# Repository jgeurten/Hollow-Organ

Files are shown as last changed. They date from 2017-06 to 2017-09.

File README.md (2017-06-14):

# Cardiac-Organ

Repo containing firmware to drive the Pololu Nema 23 item 1477 stepper motor (8.6V, 1A/phase) 190 oz-in torque using the Adafruit 'Big Easy Driver' powered by the A4988 IC.
Also included is the computer aided designed parts and assemblies designed in SolidWorks.

Adafruit Feather 32u4 BLE is the MCU on board the apparatus and uses a rotary encoder to create a closed loop feedback system enabling the usage of a PID controller.

Jordan Geurten

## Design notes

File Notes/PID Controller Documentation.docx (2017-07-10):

PID Controller Documentation

The figure bellows demonstrates a typical closed loop system for which a PID controller is modelled.

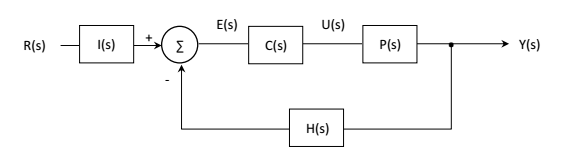
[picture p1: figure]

In PID theory, all transfer functions (e.g. R(s) are a function of s as per the Laplace domain).

R(s), the reference signal, is the input signal to the system. The difference between the output signal (Y(s)) and the reference signal should be minimized, by the closed loop system.

I(s), the input filter transfer function, converts the input signal to a usable form for the controller.

C(s), the controller transfer function, is the brain of the system, responsible for minimizing error between the reference and output. PID (proportional plus integral plus derivative controllers) are a type of controller transfer function. For PID, C(s) is equal to the expression below:

C(s)=(KdS^2 +KpS+Ki)/s (1)

E(s), error signal, is the difference between the output of the input filter function and the feedback transfer function H(s).

U(s), controller output signal, is the signal that the controller calculates and applies to the plant (in our case, the rotating jig and its associated physical terms like inertia).

Plant Transfer function P(s)

The plant transfer function is derived using one of two techniques. The first technique, ‘First Principles Techniques’ can be used when enough information is known about the system. For a mechanical system, a free body diagram of the plant is created, to which Newton’s Second Laws of motion are applied. For the rotating jig system, rotational motion is the focus:

∑ Τ=Ia (2)

The second approach, ‘Transient and Steady-State Response Analysis’ is used when scarce amounts of information is known about the plant. A known signal is applied to the plant, such as a step function of an arbitrary voltage value, and the steady – state response of the plant is analyzed.

Rotating Jig Plant Specs:

It is essential for the controller function, more specifically determining the gain values for the controller in equation 1, to determine the performance specifications of the system. Since the jig will rotate for 30 – 60 minutes, rise time will be ignored. Furthermore, maximum overshoot is not of utmost importance, either. For this reason, maximum percent overshoot will be limited to 25% for a step input. Lastly, zero steady-state error for a step input is also required. In other words, the actual speed of the system minus the desired speed of the system will equal zero.

The specifications of the system can be summarized as the following:

1. Maximum percent overshoot < 25% for a step input (derivative controller)
2. Steady-state error = 0 for a step input (Integral controller)

For these specifications, a

Modelling Each Element:

1. Stepper Motor System:

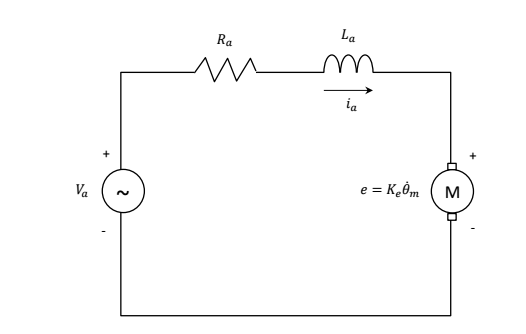
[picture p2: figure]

Using KVL on the motor’s electric armature results in:

0=Ri+L(di)/(dt)+Keϑ-V (3)

According the stepper motor’s datasheet (pololu.com/product/1477), the Nema 23 stepper has the following specs:

R = 8.6 Ohms

I

Spec | Value
R | 8.6 Ohms
i | 0.06 A
V | 12 V
L | 0.014 H
Ke | ??

2. DC Motor System:

Spec | Value
R | 8.6 Ohms
i | 0.06 A
V | 12 V
L | 0.014 H
Ke | ??

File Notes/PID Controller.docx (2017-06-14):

PID Controller – Motor Speed & Arduino

PID controller for speed reference:

http://ctms.engin.umich.edu/CTMS/index.php?example=MotorSpeed&section=ControlPID

Arduino Reference:

http://blog.solutions-cubed.com/pid-motor-control-with-an-arduino/

*Need to think if it is worth the extra work of implementing a PID controller (think testing, too) for the spinning jig project*

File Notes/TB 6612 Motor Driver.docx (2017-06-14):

TB 6612 Motor Driver – ADAFRUIT

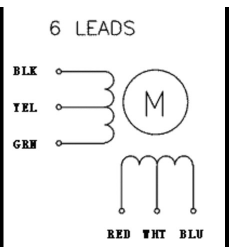
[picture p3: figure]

1. Power Pins

Vmotor – connect to battery + terminal (4.5V to 13.5V)

Vcc – connect to 3V on Feather. Voltage for logic levels (i.e. reference). Power the chip.

GND – connect all the grounds together. Shared logic and motor ground.

2. Motor out Pins

Motor A – controlled by INA1, INA2, PWMA

Motor B – same as above but with suffix ‘B’

3. Signal in Pins

INA – inputs to the motor H-bridges

PWMA – PWM input. Connect to HIGH if PWM is unnecessary

STBY – disabling motors. Connect to GND to disable. Pulled up to Vcc through a 10k resistor (built-in I believe).

Channel Configuration

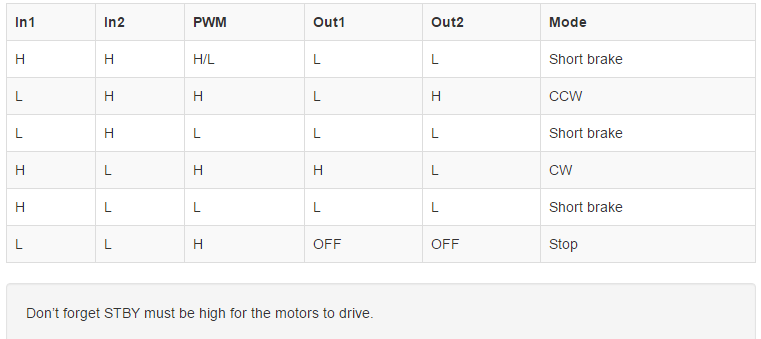
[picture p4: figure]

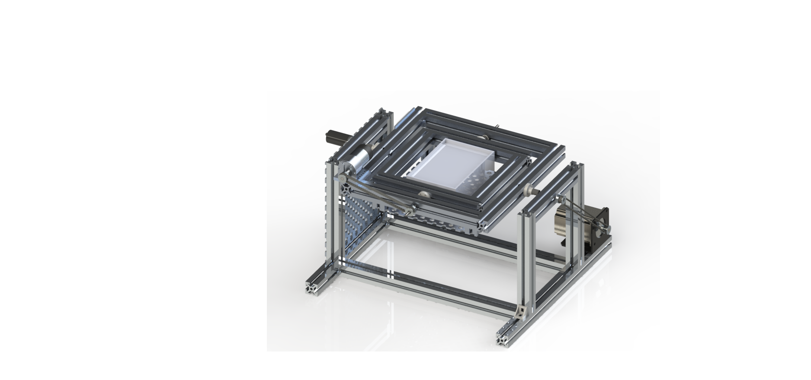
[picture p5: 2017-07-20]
Final Rendering.png

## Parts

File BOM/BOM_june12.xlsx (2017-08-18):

BOM # | Quantity | Description | Link | Length | ID | Purpose | Cost
1 | 2 | T Slotted Handle | https://www.mcmaster.com/#47065t164/=181dc2a | n/a |  | Handles for external frame | $12.80
2 | 1 | MXL Timing Belt | https://www.mcmaster.com/#7887k225/=18dpk54 | 12.2 |  | Belt for DC Motor | $3.48
3 | 1 | MXL Timing Belt | https://www.mcmaster.com/#7887k91/=18dpllq | 20 |  | Belt for Stepper Motor | $5.77
5 | 1 | Spacer Stock | https://www.mcmaster.com/#92377a310/=181ffhf | 12 inch | 0.192 | Spacer for rotary shafts | $4.44
6 | 2 | T Slotted Framing | https://www.mcmaster.com/#47065t801/=186kah1 | 6.5 inch |  | Inner-most gantry | $7.98
7 | 2 | T Slotted Framing | https://www.mcmaster.com/#47065t801/=186kah1 | 8.5 inch |  | Inner-most gantry | $10.26
8 | 4 | T Slotted Framing | https://www.mcmaster.com/#47065t801/=186kah2 | 1.5 inch |  | Inner-most gantry | $4.56
9 | 2 | T Slotted Framing | https://www.mcmaster.com/#47065t801/=186kah3 | 10 inch |  | Outer gantry | $11.40
10 | 2 | T Slotted Framing | https://www.mcmaster.com/#47065t801/=186kah3 | 12 inch |  | Outer gantry | $13.68
11 | 4 | T Slotted Framing | https://www.mcmaster.com/#47065t801/=186kah4 | 8.25 inch |  | Frame | $20.52
12 | 2 | T Slotted Framing | https://www.mcmaster.com/#47065t801/=186kah5 | 6.5 inch |  | Frame | $7.98
13 | 2 | T Slotted Framing | https://www.mcmaster.com/#47065t801/=186kah6 | 14.5 inch |  | Frame | $17.10
14 | 2 | T Slotted Framing | https://www.mcmaster.com/#47065t801/=186kah7 | 16 inch |  | Frame | $18.24
15 | 40 | Framing Brace | https://www.mcmaster.com/#47065t216/=18jckzp | 1 inch |  | Framing brace | $220.40
16 | 1 (PACK OF 10) | Threaded Rod | https://www.mcmaster.com/#95412a891/=18dok42 | 3 INCH | 10-24 | Securing mold to gantry | $7.42
17 | 4 | 4 Arm Threaded Knob | https://www.mcmaster.com/#5993k13/=18dol11 | 0 | 10-24 | Securing mold to gantry | $6.48
18 | 1 (PACK OF 50) | S.S. Hex Nut | https://www.mcmaster.com/#91841a011/=18dolm5 | 0 | 10-24 | Securing mold to gantry | $3.50
19 | 1 | DC Motor L-Bracket | https://www.pololu.com/product/1084 | 0 |  | Securing DC motor | $7.95
20 | 1 | Stepper Motor L-Bracket | https://www.pololu.com/product/2258 | 0 |  | Securing Stepper Motor | $4.95
21 | 1 | Mounting plate (3"x3") | https://www.mcmaster.com/#47065t854/=188kx18 | 3x3 |  | Securing Stepper to Rig | $12.56
22 | 2 | Mounting plate (3" x 1.5") | https://www.mcmaster.com/#47065t853/=188kxoe | 3x1.5 |  | DC motor circuit/MCU | $24.28
23 | 1 | Mounting plate (2" x 2") | https://www.mcmaster.com/#47065t852/=188kyri | 2x2 |  | DC Motor mount | $11.32
24 | 2 | NiCad Battery 12 Volt 1800 mAh | https://www.digikey.ca/product-detail/en/panasonic-bsg/KR1800SCEL5X2/SY156-L052-ND/1985934 | 8.33 inch |  | Battery for stepper and DC motor | $144.86
25 | 2 | LiPoly Battery 3.V 500 mAh | https://elmwoodelectronics.ca/products/lithium-ion-polymer-battery-3-7v-500mah | 1.15 inch |  | Battery for MCUs | $23.98
26 | 1 | NiCad Battery Charger (180 mA) | https://elmwoodelectronics.ca/products/10473 | N/A |  | Charging for NiCad Bat | $43.99
27 | 2 | JST Cable Set | https://elmwoodelectronics.ca/products/2-pin-jst-sm-plug-receptacle-cable-set | 16 cm |  | For NiCd Battery | $6.98
28 | 2 | JST Male | https://elmwoodelectronics.ca/products/jst-2-pin-cable | 10 cm |  | For NiCd Battery | $6.98
29 | 2 | JST Extension | https://elmwoodelectronics.ca/products/jst-ph-battery-extension-cable-500mm | 50 cm |  | For NiCd Battery | $9.18
30 | 8 | Sealed Ball Bearing | https://www.mcmaster.com/#60355k861/=18dprn8 | 0.2 | 3/16 |  | $24.96
 |  |  |  |  |  |  | $673.04

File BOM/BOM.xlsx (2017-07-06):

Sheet: Sheet1
Bill of Materials |  | List Number | Quantity | Part Number | Description | ID (in) | OD (in) | Pitch (in) | # Teeth | Max Belt Width | Length (in) | Website Hyperlink
Project: | Rotating Jig | 1 | 2 | 1375K36 | Timing Belt Pulley | 3/16 | 0.635 | 0.08 | 18 | 1/4 |  | https://www.mcmaster.com/#1375k36/=17jge2d
Engineer: | Jordan Geurten | 2 | 8 | 60355K502 | Ball Bearing | 3/16 | 0.5 | N/A | N/A | N/A | 5/32 | https://www.mcmaster.com/#60355k502/=17jgp9q
 |  | 3 | 2 | 1327K53 | 12L14 Carbon Steel Shaft | N/A | 3/16 | N/A | N/A | N/A | 12 | https://www.mcmaster.com/#1327k53/=17jgfdh
* Spare parts |  | 4 | 4 | 6436K6 | Face Mount Shaft Collar | 3/16 | 5/8 | N/A | N/A | N/A | 5/16 | https://www.mcmaster.com/#6436k6/=17jghuk
^* To start and stop the device |  | 5 | 1 | 90044A111 | 4-40 Alloy Steel Socket Head Scres | 0.112 | 0.183 | N/A | N/A | N/A | 1 | https://www.mcmaster.com/#90044a111/=17jgmsh
 |  | 6 | 2 |  | Low Speed Torque Stepper Motor |  | https://www.pololu.com/category/87/stepper-motors
 |  | 7 | 4 |  | Rechargable Battery
 |  | 8 | 2 |  | Arduino Microcontroller
 |  | 9 | 2 |  | Stepper Motor Controller
 |  | 12 |  |  | Drive Belts

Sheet: Stepper Motor
List Number | Quantity | Part Number | Description | Holding Torque | Steps/rev | Current Draw (A) | Voltage (v) | Shaft Diam | Size | Belt Size | Price per unit | Total Price | Website Hyperlink
6 | 2 | 1477 | Pololu Stepper Motot | 14kg-cm | 200 | 1 | 8.6 | 6.35mm | 56.4*76 |  | $49.95 | $99.90 | https://www.pololu.com/product/1477
7 | 2 | 1375K39 | Timing Belt Pulley |  |  |  |  | For 6.35mm |  | 1/4 " | $10.79 | $21.58 | https://www.mcmaster.com/#1375k39/=17oixwq
8 | 2 | 2448 | Stepper Motor Driver |  |  | <1.2 | 5-13.5 |  |  |  | 4.95 | $9.90 | https://www.adafruit.com/product/2448
9 | 2 | 2829 | Microcontroller with BLE |  |  |  |  |  |  |  | 29.95 | $59.90 | https://www.adafruit.com/product/2829
10 | 2 | 2830 | Stacking Headers |  |  |  |  |  |  |  | 1.25 | $2.50 | https://www.adafruit.com/product/2830
11 | 1 |  | Power pigtails |  |  |  |  |  |  |  | 3.61 | $3.61 | https://www.amazon.ca/uxcell-5-5X2-1mm-Connector-Pigtail-Camera/dp/B01L7NC85S
12 | 2 |  | Power Banks |  |  |  |  |  |  |  | 84.99 | $169.98 | https://www.amazon.ca/dp/B01LRW4DUC?psc=1
 |  |  |  |  |  |  |  |  |  |  | total: | $367.37

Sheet: Battery Packs
http://www.batteryspace.com/custom-nimh-battery-flat-pack-12v-2200mah-10xaa-with-2a-polyswitch.aspx
12 V
2200 mAh
https://www.amazon.ca/RAVPower-23000mAh-Portable-External-Smartphones/dp/B00HFMUBYG
12V
23000 mAh
https://www.newegg.com/Product/Product.aspx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
12V
20000mAh

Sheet: Mcmaster Carr
List Number | Quantity | Part Number | Description | ID (in) | OD (in) | Pitch (in) | # Teeth | Max Belt Width | Length (in) | Website Hyperlink
1 | 2 | 1375K36 | Timing Belt Pulley | 3/16 | 0.635 | 0.08 | 18 | 1/4 |  | https://www.mcmaster.com/#1375k36/=17jge2d
2 | 8 | 60355K502 | Ball Bearing | 3/16 | 0.5 | N/A | N/A | N/A | 5/32 | https://www.mcmaster.com/#60355k502/=17jgp9q
3 | 2 | 1327K53 | 12L14 Carbon Steel Shaft | N/A | 3/16 | N/A | N/A | N/A | 12 | https://www.mcmaster.com/#1327k53/=17jgfdh
4 | 4 | 6436K6 | Face Mount Shaft Collar | 3/16 | 5/8 | N/A | N/A | N/A | 5/16 | https://www.mcmaster.com/#6436k6/=17jghuk
5 | 1 | 90044A111 | 4-40 Alloy Steel Socket Head Scres | 0.112 | 0.183 | N/A | N/A | N/A | 1 | https://www.mcmaster.com/#90044a111/=17jgmsh

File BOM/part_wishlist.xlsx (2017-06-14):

List Number | Quantity | Part Number | Description | Price per unit | Total Price | Website Hyperlink
6 | 1 | 1477 | Pololu Stepper Motor | $49.95 | $49.95 | https://www.pololu.com/product/1477
7 | 2 | 1375K39 | Timing Belt Pulley | $10.79 | $21.58 | https://www.mcmaster.com/#1375k39/=17oixwq
8 | 1 | 2448 | Stepper Motor Driver | $4.95 | $4.95 | https://www.adafruit.com/product/2448
9 | 2 | 2829 | Microcontroller with BLE | $29.95 | $59.90 | https://www.adafruit.com/product/2829
10 | 2 | 2830 | Stacking Headers | $1.25 | $2.50 | https://www.adafruit.com/product/2830
11 | 1 |  | Power pigtails | $3.61 | $3.61 | https://www.amazon.ca/uxcell-5-5X2-1mm-Connector-Pigtail-Camera/dp/B01L7NC85S
12 | 2 |  | Power Banks | $84.99 | $169.98 | https://www.amazon.ca/dp/B01LRW4DUC?psc=1
13 | 1 | COM-10932 | Rotary Encoder | $39.95 | $39.95 | https://www.sparkfun.com/products/10932
15 | 1 |  | Brushed DC Motor with Encoder | $51.94 | $51.94 | https://www.pololu.com/product/2824
16 | 1 | 976 | TIP 120 Transistor | $2.50 | $2.50 | https://www.adafruit.com/product/976
17 | 1 | 755 | 1N4001 Diodes | $1.50 | $1.50 | https://www.adafruit.com/product/755
18 | 1 | 753 | 0.1 uF Capacitors | $1.95 | $1.95 | https://www.adafruit.com/product/753
19 | 1 | 1214 | 3 Pack Protoboard PCB | $7.95 | $7.95 | https://www.adafruit.com/product/1214
20 | 2 | MCP602T-I/SN | Integrated Circuit Microchip | $0.92 | $1.84 | https://www.digikey.ca/product-detail/en/microchip-technology/MCP602T-I-SN/MCP602T-I-SNCT-ND/5013529
21 | 2 | IRLZ44NPBF | MOSFET Transistor | $1.44 | $2.88 | https://www.digikey.ca/product-detail/en/infineon-technologies/IRLZ44NPBF/IRLZ44NPBF-ND/811808
 |  |  |  | total: | $418.25

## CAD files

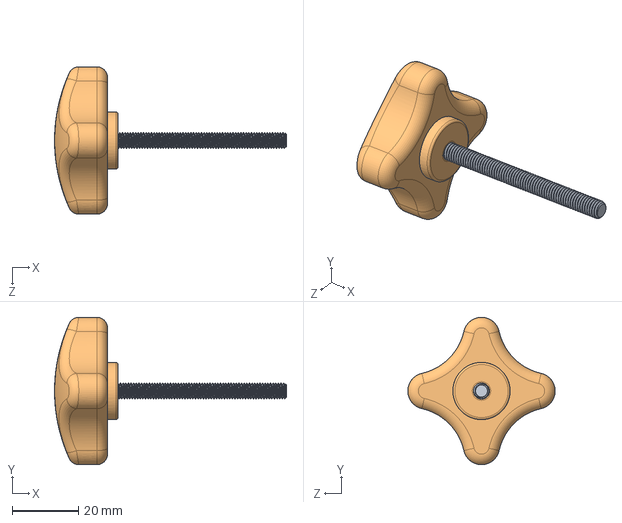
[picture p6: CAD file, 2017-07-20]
CAD/Assemblies/Mold_Clamp_revB.SLDASM
70.0 x 44.4 x 44.4 mm
10-32_rod
threaded_four_arm_knob

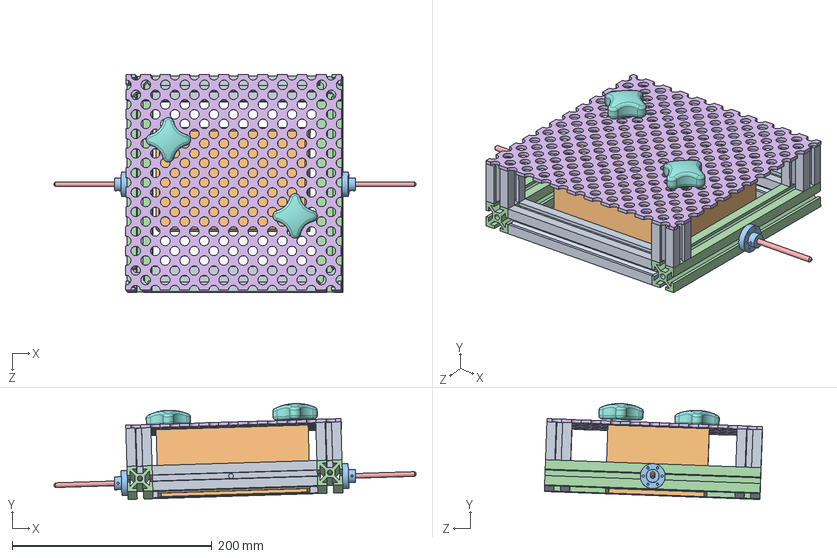
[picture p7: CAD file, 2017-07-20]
CAD/Assemblies/Inside Gantry.SLDASM
362.5 x 96.1 x 218.2 mm
1_1_frame_6_8inch x 2
Kidney_Mold
Face_Shaft_Collar_revA x 2
1_1_frame_7inch x 2
rotary_shaft x 2
framing_panel_inside
10-32_rod x 2
threaded_four_arm_knob x 2
1_1_frame_1_inch x 4

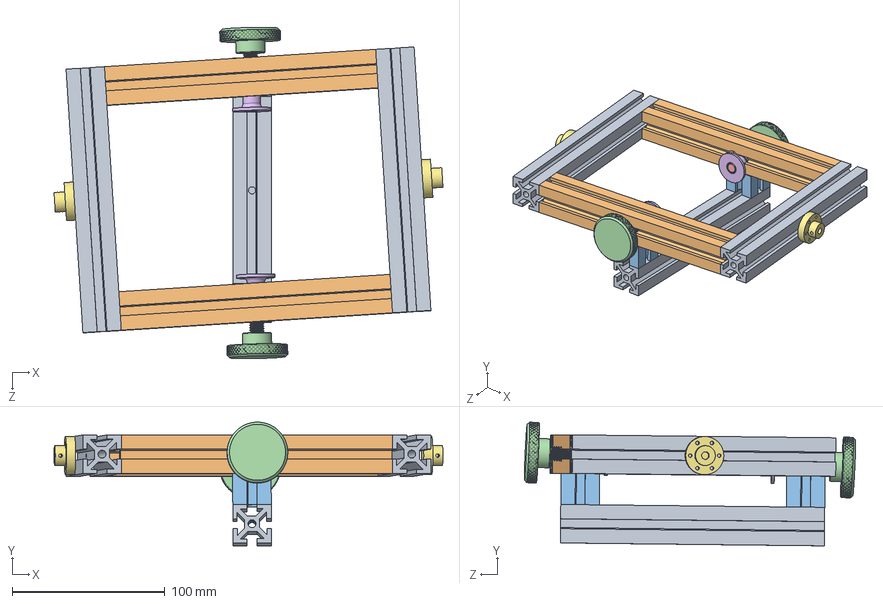
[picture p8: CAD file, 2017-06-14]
CAD/Assemblies/Mold_Jig.SLDASM
254.5 x 81.0 x 216.8 mm
1_1_frame_6_8inch x 3
1_1_frame_7inch x 2
1_1_frame_0_8_inch x 2
Knurled_Knob x 2
Threaded_Rod_Clamp x 2
Base_Nut x 2
Face_Shaft_Collar_revA x 2

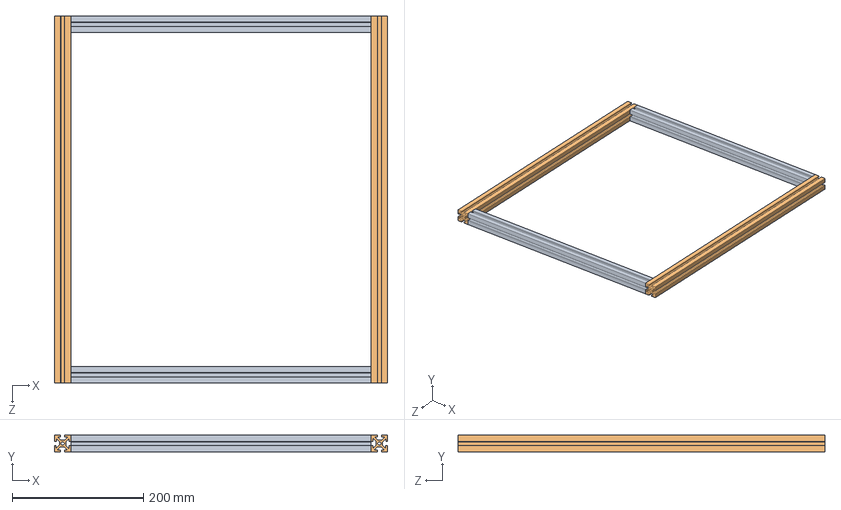
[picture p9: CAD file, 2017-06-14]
CAD/Assemblies/external_frame_top_bot.SLDASM
507.6 x 25.2 x 558.8 mm
1_1_frame_18_inch x 2
1_1_frame_22_inch x 2

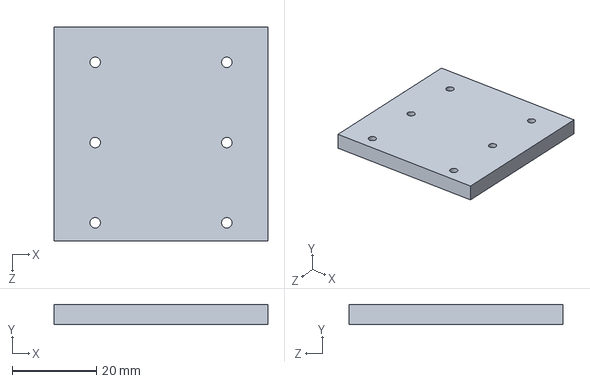
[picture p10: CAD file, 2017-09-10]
CAD/SLDPRTs/dc_motor_platform_alumin.SLDPRT
50.8 x 4.83 x 50.8 mm

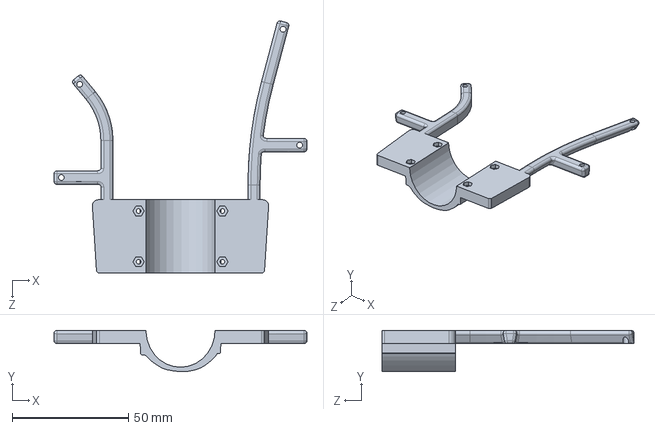
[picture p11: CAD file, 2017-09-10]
CAD/SLDPRTs/laser_drb_revB.SLDPRT
108.9 x 17.8 x 108.6 mm

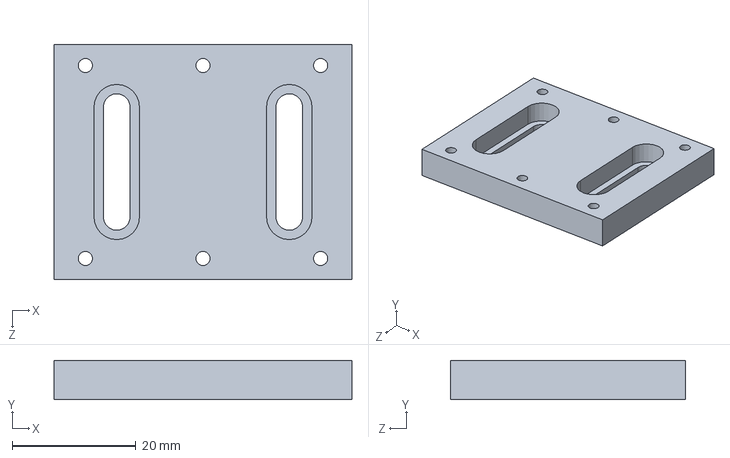
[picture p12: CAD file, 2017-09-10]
CAD/SLDPRTs/dc_motor_platform.SLDPRT
48.3 x 6.35 x 38.1 mm

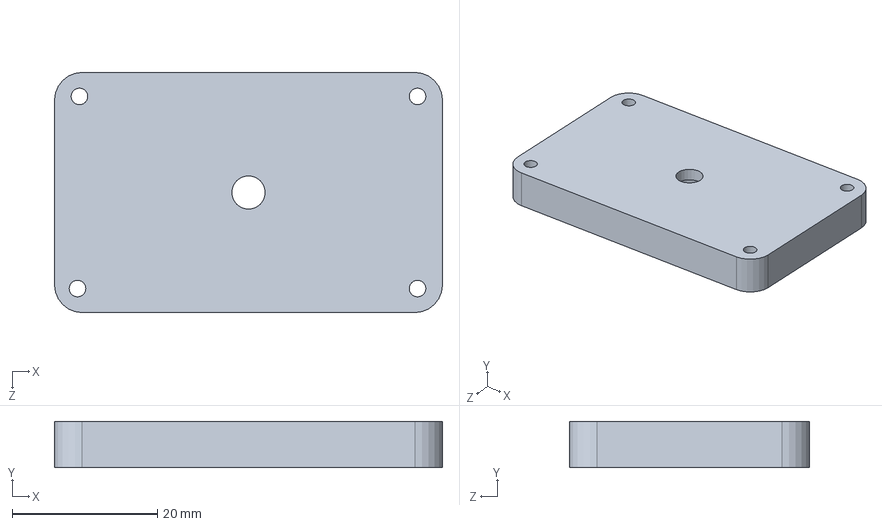
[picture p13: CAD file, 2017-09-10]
CAD/SLDPRTs/dc_mcu_platform.SLDPRT
53.3 x 6.35 x 33.0 mm

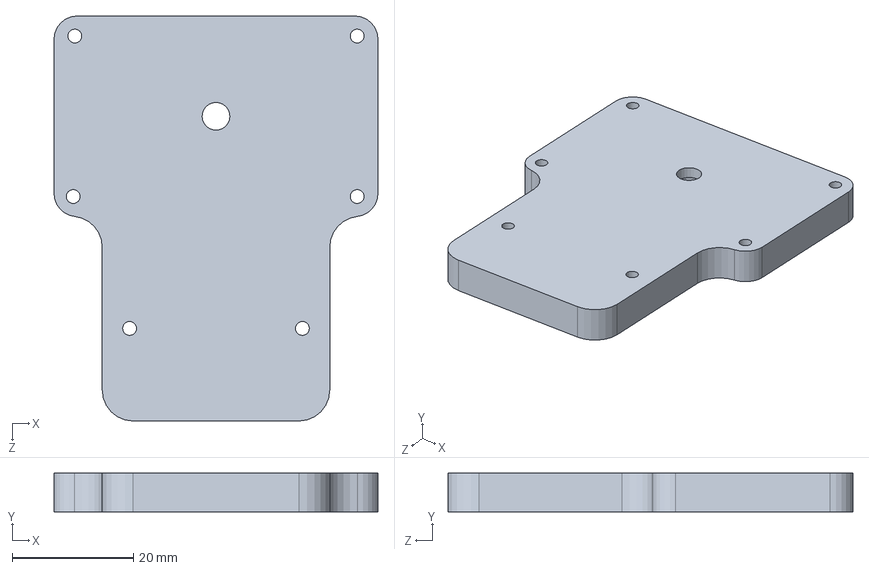
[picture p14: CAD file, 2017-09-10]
CAD/SLDPRTs/stepper_driver_platform.SLDPRT
53.3 x 6.35 x 66.7 mm

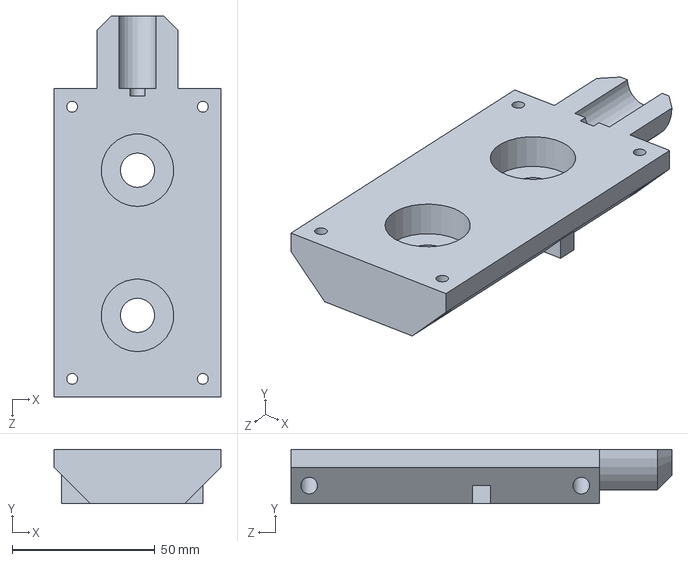
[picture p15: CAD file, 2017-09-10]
CAD/SLDPRTs/Endo_top_half.SLDPRT
58.4 x 19.1 x 133.4 mm

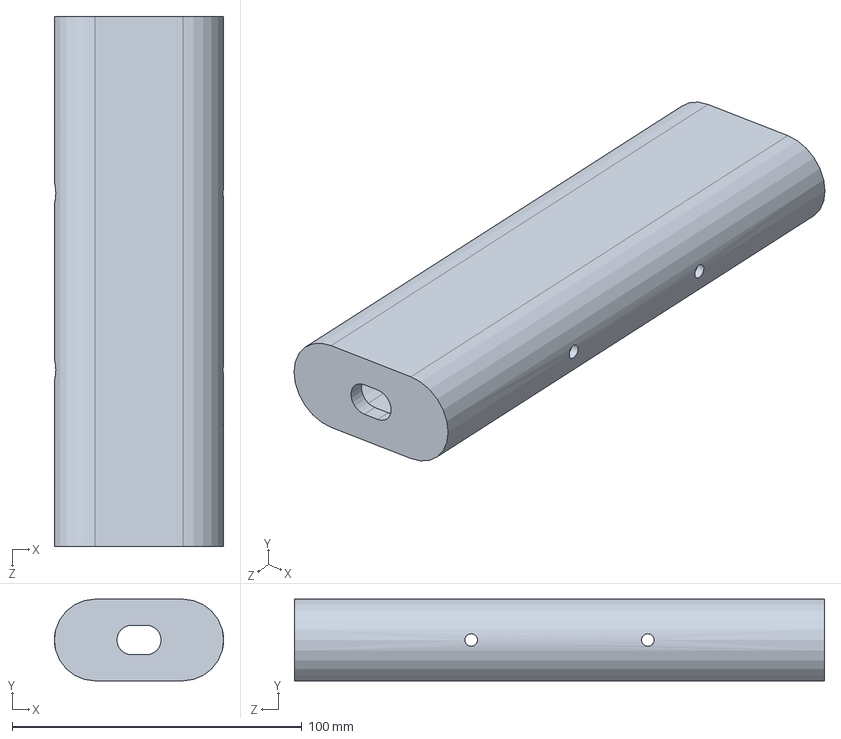
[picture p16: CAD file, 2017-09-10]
CAD/SLDPRTs/battery_shield_RevB.SLDPRT
58.4 x 28.2 x 182.9 mm

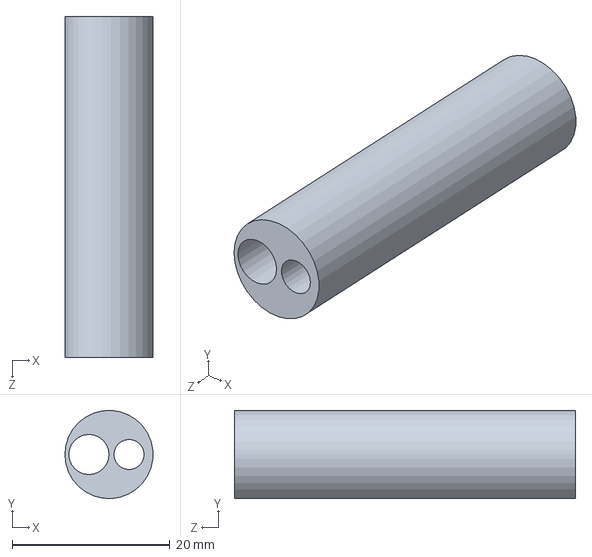
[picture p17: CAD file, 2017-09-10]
CAD/SLDPRTs/laserSheath.SLDPRT
11.2 x 11.2 x 43.2 mm

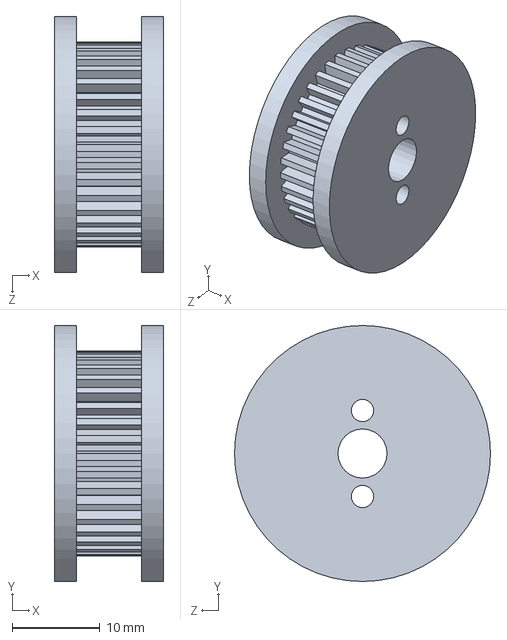
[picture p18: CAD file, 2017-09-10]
CAD/SLDPRTs/2to1_TimingBelt.SLDPRT
12.4 x 29.1 x 29.1 mm

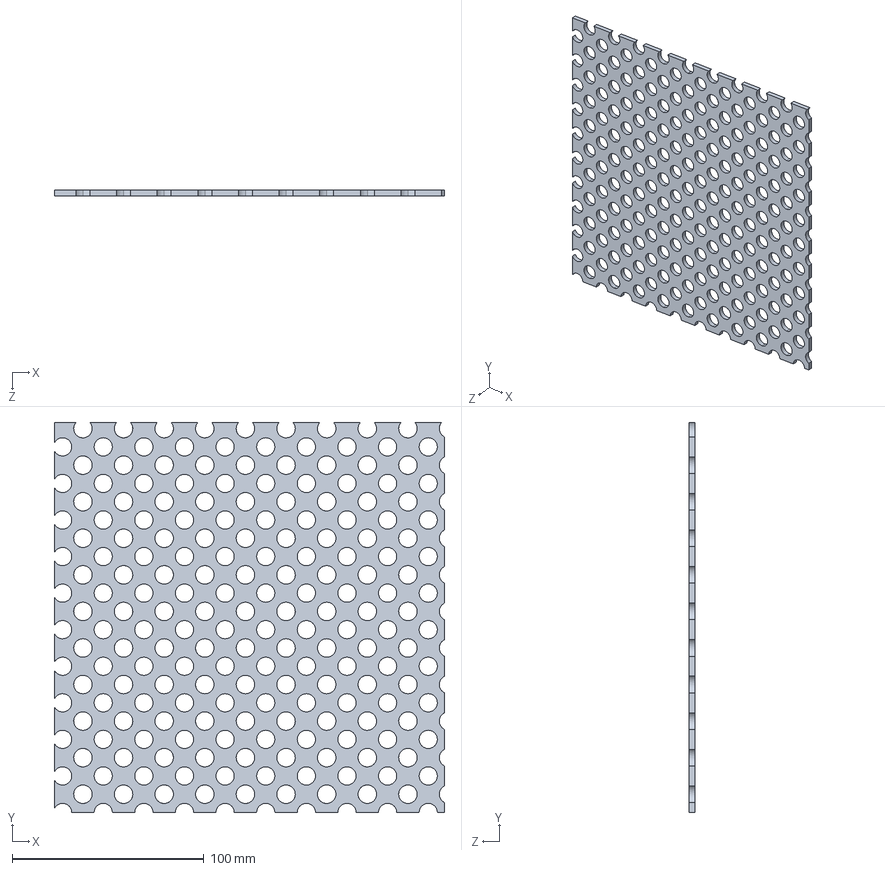
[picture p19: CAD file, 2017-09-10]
CAD/SLDPRTs/framing_panel.SLDPRT
203.2 x 203.2 x 3.17 mm

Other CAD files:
CAD/SLDPRTs/MCU_Battery_shield.SLDPRT
CAD/Assemblies/Mold_Clamp.SLDASM
CAD/Assemblies/Mold_Clamp_revA.SLDASM
CAD/SLDPRTs/10-32_rod.SLDPRT
CAD/SLDPRTs/1375K110_MXL SERIES TIMING BELT PULLEY.SLDPRT
CAD/SLDPRTs/1_1_frame_0_8_inch.SLDPRT
CAD/SLDPRTs/1_1_frame_18_inch.SLDPRT
CAD/SLDPRTs/1_1_frame_1_inch.SLDPRT
CAD/SLDPRTs/1_1_frame_22_inch.SLDPRT
CAD/SLDPRTs/1_1_frame_6_8inch.SLDPRT
CAD/SLDPRTs/1_1_frame_7inch.SLDPRT
CAD/SLDPRTs/1_1_frame_true18_inch.SLDPRT
CAD/SLDPRTs/1by1by10inch_frame.SLDPRT
CAD/SLDPRTs/1by1by11inch_frame.SLDPRT
CAD/SLDPRTs/1by1by4_5inch_frame.SLDPRT
CAD/SLDPRTs/1by1by9inch_frame.SLDPRT
CAD/SLDPRTs/2776K200_POLYPROPYLENE COMFORT-GRIP 3-ARM KNOB.SLDPRT
CAD/SLDPRTs/47065T164_ALUMINUM T-SLOTTED FRAMING EXTRUSION.SLDPRT
CAD/SLDPRTs/47065T216_ALUMINUM T-SLOTTED FRAMING EXTRUSION.SLDPRT
CAD/SLDPRTs/47065T901_ALUMINUM T-SLOTTED FRAMING EXTRUSION.SLDPRT
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

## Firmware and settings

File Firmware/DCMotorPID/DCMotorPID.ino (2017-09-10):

   ///////////////////////////////////////////////////////////////////////////////////////////
  // DC Motor PID Controller Code
  // Version 1, July 10
  // Jordan Geurten
  ///////////////////////////////////////////////////////////////////////////////////////////
  
  #include <math.h>
  #include <MsTimer2.h>
  
  ///////////////////////////////////////////////////////////////////////////////////////////
  // Motor pins
  ///////////////////////////////////////////////////////////////////////////////////////////
  
  unsigned int stopPin =     1;             //feather interrupt pin2
  unsigned int startPin =    0;             //feather interrupt pin3
  unsigned int encoderPin =  2;             //feather interrupt pin1
  unsigned int voltagePin =  3;             //feather interrupt pin0
  unsigned int motorPin =    5;

  unsigned int Motor_Current;               //Pin to read current input from motor controller. WAit, we dont have a motor controller. 
  
  //Global variables:
  
  volatile byte Go = 0;                      //Interrupt flag for START
  volatile byte Stop = 0;                    //Interrup flag for STOP
  volatile double Error = 0;                 //Ref_Speed Error
  volatile double prevError = 0;             //Prev Ref_Speed Error
  volatile double KpOutput = 0;              //Proportional output
  volatile double KiOutput = 0;              //Integral output
  volatile double KdOutput = 0;              //Derivative output
  volatile double Controller_Input = 0;       //Output from Error calc
  volatile double VtoPWM = 0;                //Define relation between voltage and pwm
  volatile double Integral= 0;               //Integral of the error
  
  volatile unsigned long edgeCount = 0;      //Encoder edge count
  volatile double Motor_Speed = 0;            //Motor Ref_Speed in RPM
  volatile float Elapsed_Time = 0;           //Elapsed time of the test
  volatile double startTime = 0;             //Store last time start button was pressed
  volatile double stopTime = 0;              //Store last stop button time
  
  ///////////////////////////////////////////////////////////////////////////////////////////
  //User defined variables:
  ///////////////////////////////////////////////////////////////////////////////////////////
  
  double Kp = 0;                             //Proportional gain
  double Ki = 0;                             //Integral gain
  double Kd = 0;                             //Derivative gain
  
  //Define input voltage
  float V_in  = 12.0;
  
  //Timer timeout period in ms
  static unsigned int Period = 50;
  
  //Desired Speed [in RPM]
  static unsigned int Ref_Speed =  30;
  
  //Open loop variables [in RPM]
  volatile float Ref_Input = 0;

  //Open loop variable - step input [PWM]
  volatile float Step_Input = 0;

  //Duration of the test [in seconds]:
  volatile float Time = 5 * 60;           //5 minute test * 60 secs/min 

  

  //
  //////////////////////////////////////////////////////////////////////////////////////////
  // Mode of Operation:
  //
  //      0 = Open Loop Step    -- applies a constant voltage to motor
  //                            Inputs  ---------------------------------------------------
  //                            Step_Input -- sets the duty cycle of PWM output; an integer
  //                                          value between 0 and 255
  //                            I_Gain -- Gain of Input Filter function I(s) in encoder counts/radians
  //                            Time -- sets the duration of the test in seconds
  //
  //                            Outputs ---------------------------------------------------
  //                            Reference_Input -- duty cycle of PWM output; an integer value
  //                                               between 0 and 255
  //                            Time -- sets the duration of the test in seconds
  
  //
  //      1 = Closed Loop Step    -- PID Controller
  //                            Inputs  ---------------------------------------------------
  //                            Kp, Ki, Kd -- Proportional, integral, derivative gains, respectively
  //                            Time -- sets the duration of the test in seconds
  
  //                            Outputs ---------------------------------------------------
  
  //                            Reference_Input -- duty cycle of PWM output; an integer value
  //                                               between 0 and 255
  //                            Time -- sets the duration of the test in seconds
  
  
  ///////////////////////////////////////////////////////////////////////////////////////////
  //Declare mode of operation:
  
  static byte mode = 0;
  
  ///////////////////////////////////////////////////////////////////////////////////////////
  //Functions:
void  encoderISR(); 
void  TimerISR();
void  StopMotor(); 
void  START(); 
void  STOP(); 
void  ClosedLoopStep(); 
void  RunMotor(); 
void  OpenLoopStep(); 
  
  
  //ISR to increment count of encoder to count its square wave frequency
  void encoderISR()
  {
    edgeCount++;
  }
  
  void TimerISR()
  {
    Elapsed_Time++; 
    Motor_Speed = (double) edgeCount * 60 / (2 * 16 * 50) / Period;
    // multiply by the gear ratio (50:1) divided by 1 second [revolutions/minute]
  
    if (mode == 0)
      OpenLoopStep();                       //get constant voltage value
  
    if (mode == 1)
      ClosedLoopStep();                     //get error from motor speed and ref_speed

    RunMotor(Controller_Input); 
  
    edgeCount = 0;                          //Reset encoder count
  }
  
  //Function to stop motor:
  void StopMotor()
  {
    analogWrite(motorPin, 0);                  //Cut voltage to motor
    digitalWrite(voltagePin, LOW);
  }
  
  //Interrupt function to start system:
  void START()
  {
    if(millis() - startTime > 1500)
    {
    Stop = 0;
    Go = 1;
    Serial.println("Gopressed"); 
    startTime = millis(); 
    }
  }
  
  //Interrupt function to stop system:
  void STOP ()
  {
    if(millis() - stopTime > 1000)
    {
    Stop = 1;
    Go = 0;
    StopMotor();
    Serial.println("Stop pressed");
    stopTime = millis(); 
    }
  }
  
  //call during Timer1 OVF ISR
  
  void ClosedLoopStep()
  {
    Error = Ref_Speed - Motor_Speed;
    if (Kp > 0)
    {
      KpOutput = Kp * Error;
      Controller_Input = KpOutput;
    }
  
    if (Kd > 0)
    {
      KdOutput = Kd * (Error - prevError)/Period; // dx/dt = delta error/delta time(a.k.a. period)
      Controller_Input += KdOutput;
    }
  
    if (Ki > 0)
    {
      Integral += Error * Period;                 //integral = sum of the errors*period -- integral is reset every 
      KiOutput = Ki * Integral;
      Controller_Input += KiOutput;
    }
  
    prevError = Error;
    Controller_Input *= VtoPWM;
  }
  
  void RunMotor(float input)
  {
    if (!Stop && Go)
    {
      input = abs(input);
      if (input > 255)
        input = 255;
  
      analogWrite(motorPin, input);
      Serial.println("Running motor"); 
    }
  }
  
  void OpenLoopStep()
  {
    Controller_Input = Step_Input;
    Ref_Input = Controller_Input;
  }
  
  void setup()
  {
    Serial.begin(9600);
    pinMode(encoderPin, INPUT);         //encoder ISR
    pinMode(startPin, INPUT);           //START ISR
    pinMode(stopPin, INPUT);            //STOP ISR
    pinMode(motorPin, OUTPUT);
    pinMode(voltagePin, OUTPUT);
    digitalWrite(voltagePin, HIGH);
    
    MsTimer2::set(Period, TimerISR);
    attachInterrupt(digitalPinToInterrupt(encoderPin), encoderISR, CHANGE);
    attachInterrupt(digitalPinToInterrupt(stopPin), STOP, RISING);
    attachInterrupt(digitalPinToInterrupt(startPin), START, RISING);
  
    VtoPWM = 255 / V_in;
    
    MsTimer2::start();
  }
  
  void loop()
  {
    if(Go)
    {
      RunMotor(75); 
      delay(2); 
    }

    if(Elapsed_Time*Period/1000 > Time) //End of run
    {
      StopMotor(); 
      Serial.println("Finished."); 
      while(1){};   //Require MCU reset
    }
     
  }

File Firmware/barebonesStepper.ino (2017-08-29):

#include <MsTimer2.h>

///////////////////////////////////////////////////////////////////////////////////////////
// DC Motor PID Controller Code
// Version 1, July 10
// Jordan Geurten
///////////////////////////////////////////////////////////////////////////////////////////

#include <math.h>
#include <MsTimer2.h>

///////////////////////////////////////////////////////////////////////////////////////////
// Motor pins
///////////////////////////////////////////////////////////////////////////////////////////


#define  ENCA     0  //Interrupt encoder pin1
#define  ENCB     1  //Interrupt encoder pin2
#define  GOPIN    2  //Interrupt go button pin
#define  STOPPIN  3  //Interrupt Stop button pin
#define  SLEEP    5
#define  RST      6
#define  MS3      9
#define  MS2      10
#define  MS1      11
#define  ENABLE   12
#define  DIR      14  //miso
#define  STEP     16  //mosi pin (also digital)

unsigned int Motor_Current;               //Pin to read current input from motor controller. WAit, we dont have a motor controller.

//Global variables:

volatile byte Go = 0;                      //Interrupt flag for START
volatile byte Stop = 0;                    //Interrup flag for STOP
volatile double Error = 0;                 //Ref_Speed Error
volatile double prevError = 0;             //Prev Ref_Speed Error
volatile double KpOutput = 0;              //Proportional output
volatile double KiOutput = 0;              //Integral output
volatile double KdOutput = 0;              //Derivative output
volatile double Controller_Input = 0;       //Output from Error calc
volatile double VtoPWM = 0;                //Define relation between voltage and pwm
volatile double Integral = 0;              //Integral of the error

volatile unsigned long edgeCount = 0;      //Encoder edge count
volatile double Motor_Speed = 0;            //Motor Ref_Speed in RPM
volatile double Elapsed_Time = 0;           //Elapsed time of the test
volatile double goTime = 0;                 //time of last go button push
volatile double stopTime = 0;               //Time of last stop button push


///////////////////////////////////////////////////////////////////////////////////////////
//User defined variables:
///////////////////////////////////////////////////////////////////////////////////////////

double Kp = 0;                             //Proportional gain
double Ki = 0;                             //Integral gain
double Kd = 0;                             //Derivative gain

//Define input voltage
float V_in  = 12.0;

//Timer timeout period in ms
double Period = 50.0;

//Desired Speed [in RPM]
static unsigned int Ref_Speed =  30;

//Open loop variables [in RPM]
volatile float Ref_Input = 0;

//Open loop variable - step input [PWM]
volatile float Step_Input = 0;

//Duration of the test [in seconds]:
volatile float Time = 15;



//
//////////////////////////////////////////////////////////////////////////////////////////
// Mode of Operation:
//
//      0 = Open Loop Step    -- applies a constant voltage to motor
//                            Inputs  ---------------------------------------------------
//                            Step_Input -- sets the duty cycle of PWM output; an integer
//                                          value between 0 and 255
//                            I_Gain -- Gain of Input Filter function I(s) in encoder counts/radians
//                            Time -- sets the duration of the test in seconds
//
//                            Outputs ---------------------------------------------------
//                            Reference_Input -- duty cycle of PWM output; an integer value
//                                               between 0 and 255
//                            Time -- sets the duration of the test in seconds

//
//      1 = Closed Loop Step    -- PID Controller
//                            Inputs  ---------------------------------------------------
//                            Kp, Ki, Kd -- Proportional, integral, derivative gains, respectively
//                            Time -- sets the duration of the test in seconds

//                            Outputs ---------------------------------------------------

//                            Reference_Input -- duty cycle of PWM output; an integer value
//                                               between 0 and 255
//                            Time -- sets the duration of the test in seconds


///////////////////////////////////////////////////////////////////////////////////////////
//Declare mode of operation:

static byte mode = 0;

///////////////////////////////////////////////////////////////////////////////////////////
//Functions (forward declare):
void  encoderISR_A();
void  encoderISR_B();
void  TimerISR();
void  goISR();
void  stopISR();
void  RunMotor();

void setup()
{
  Serial.begin(9600);

  //Motor output pins:
  pinMode(ENABLE, OUTPUT);
  pinMode(RST, OUTPUT);
  pinMode(SLEEP, OUTPUT);
  pinMode(MS1, OUTPUT);
  pinMode(MS2, OUTPUT);
  pinMode(MS3, OUTPUT);
  pinMode(STEP, OUTPUT);
  pinMode(DIR, OUTPUT);

  //Encoder input pins:
  pinMode(ENCA, INPUT);
  pinMode(ENCB, INPUT);

  //Buton input pins
  pinMode(GOPIN, INPUT);
  pinMode(STOPPIN, INPUT);

  //initialize sixteenth step
  digitalWrite(MS1, LOW);
  digitalWrite(MS2, LOW);
  digitalWrite(MS3, LOW);

  digitalWrite(DIR, LOW); //Pull pin low to move "forward"
  digitalWrite(MS1, HIGH); //Set MS1,MS2, and MS3 high to set logic to 1/16th microstep resolution
  digitalWrite(MS2, HIGH);
  digitalWrite(MS3, HIGH);

  //Encoder interrupts:
  attachInterrupt(digitalPinToInterrupt(ENCA), encoderISR_A, RISING);
  attachInterrupt(digitalPinToInterrupt(ENCB), encoderISR_B, RISING);

  //Button interrupts:
  attachInterrupt(digitalPinToInterrupt(GOPIN), goISR, RISING);
  attachInterrupt(digitalPinToInterrupt(STOPPIN), stopISR, RISING);

  MsTimer2::set(Period, TimerISR);

}
//ISR to increment count of encoder to count its square wave frequency

void TimerISR()
{
  if (Go)
  {
    Serial.println("In ISR");
    Elapsed_Time++;
    RunMotor();

    edgeCount = 0;                          //Reset encoder count
  }
}

//Function to stop motor:
void StopMotor()
{
  digitalWrite(RST, LOW);   //When set LOW, all STEP commands are ignored and all FET functionality is turned off
  digitalWrite(ENABLE, HIGH); //If set to HIGH, all FETs will be disabled, restricting motor control.
  Serial.println("Stop Motor");
  digitalWrite(SLEEP, LOW);     //When set to low, A498 enters sleep mode


}

//External interrupt to increment encoder count:
void encoderISR_A()
{
  edgeCount++;
}

void encoderISR_B()
{
  edgeCount++;
}
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

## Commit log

2017-06-14 June 14 Revisions
    [1_1_frame_0_8_inch.SLDPRT, 1_1_frame_18_inch.SLDPRT, 1_1_frame_1_inch.SLDPRT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]
2017-06-14 Added assembly STL
2017-06-21 template - pid
2017-06-22 Timer overflow attempt
2017-06-22 Updated timer code
2017-06-22 Timer and external interrupts
2017-06-22 Timers and interrupts work perfectly
2017-06-22 Added framing, motor access, mold holder
    [BOM_june12.xlsx]
2017-06-22 Correct encoder RPM
2017-06-28 Added rails after finalizing design
    [BOM_june12.xlsx]
2017-06-28 Added batteries and additional brace source
    [BOM_june12.xlsx]
2017-07-06 Added materials to BOM
    [BOM.xlsx, BOM_june12.xlsx]
2017-07-08 Initial stepper encoder commit
2017-07-10 Added PID Code and Notes
2017-07-11 Wrote calculated error function
    [DCMotorPID.ino]
2017-07-20 Finalized all CAD files
    [10-32_rod.SLDPRT, 1_1_frame_0_8_inch.SLDPRT, 1_1_frame_18_inch.SLDPRT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]
2017-07-23 Updated code for error calc, time calc.
    [DCMotorPID.ino]
2017-07-29 Added encoder interrupts
2017-07-30 Updated pins and button press interrupts
2017-08-02 Merged PID code
2017-08-18 Cleaning up REPO
    [BOM_june12.xlsx]
2017-08-29 Basic firmware for stepper motor.
2017-09-10 End of term Solid Parts commit.
    [1375K110_MXL SERIES TIMING BELT PULLEY.SLDPRT, 2to1_TimingBelt.SLDPRT, 6436K600_TWO-PIECE CLAMP-ON SHAFT COLLAR.SLDPRT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]
2017-09-10 Finalized assemblies
    [Inception_level2.SLDASM, Mold_Clamp_revB.SLDASM, assembly_june11.SLDASM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]
2017-09-10 Finalized gantry design
    [Inside Gantry.SLDASM, Outside Gantry.SLDASM]
2017-09-10 Organized repo.
    [10-32_rod.SLDPRT, 1375K110_MXL SERIES TIMING BELT PULLEY.SLDPRT, 1_1_frame_0_8_inch.SLDPRT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]
